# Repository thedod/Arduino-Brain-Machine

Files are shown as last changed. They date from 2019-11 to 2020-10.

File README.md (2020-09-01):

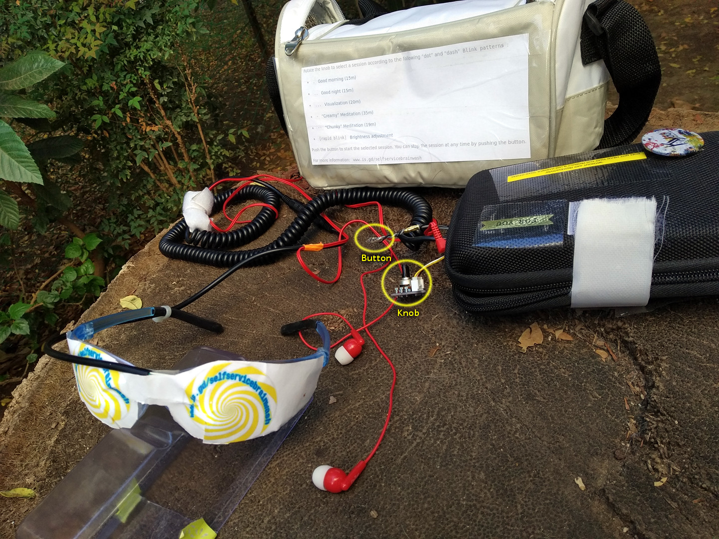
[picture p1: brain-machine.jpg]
Photo gallery (https://pixelfed.tokyo/c/89862350668173312)


For [usage instructions](https://github.com/thedod/Arduino-Brain-Machine/wiki/How-to-use)
and useful brainwave-entrainment related [links](https://github.com/thedod/Arduino-Brain-Machine/wiki/Related-links),
see [the wiki](https://github.com/thedod/Arduino-Brain-Machine/wiki).

#### Difference from fork's origin:

1. The machine can now run 5 different sessions (including the original one). Except for the the original
   session that uses [frequency hopping](https://archive.md/leNZO#selection-1151.0-1151.493) for brainwave entrainment (aka the "chunky" method), the other 4 use smooth frequency transition (aka the "creamy" method), and are based on [Mindplace](https://mindplace.com/) [Proteus](http://mindplacesupport.com/proteus/) sessions (thanks to the admins and members of the mindplace [support forum](http://mindplacesupport.com/forum/) for all the attention and knowledge). There's a 10㏀ potentiometer on pi A0 that is used to select the session.

1. Pin 2 (that used to be the "wake up button") now has 3 functions (depending on state): start / stop / wake (from sleep mode), and the button's interrupt is always attached (not only during sleep mode).

1. More serial debug prints (note that all serial related code is now
   inside `#ifdef DEBUG` blocks).

**Note:** you should download Bhagman's `Tone` library [here](https://github.com/bhagman/Tone#readme).

#### Example breadboard setup
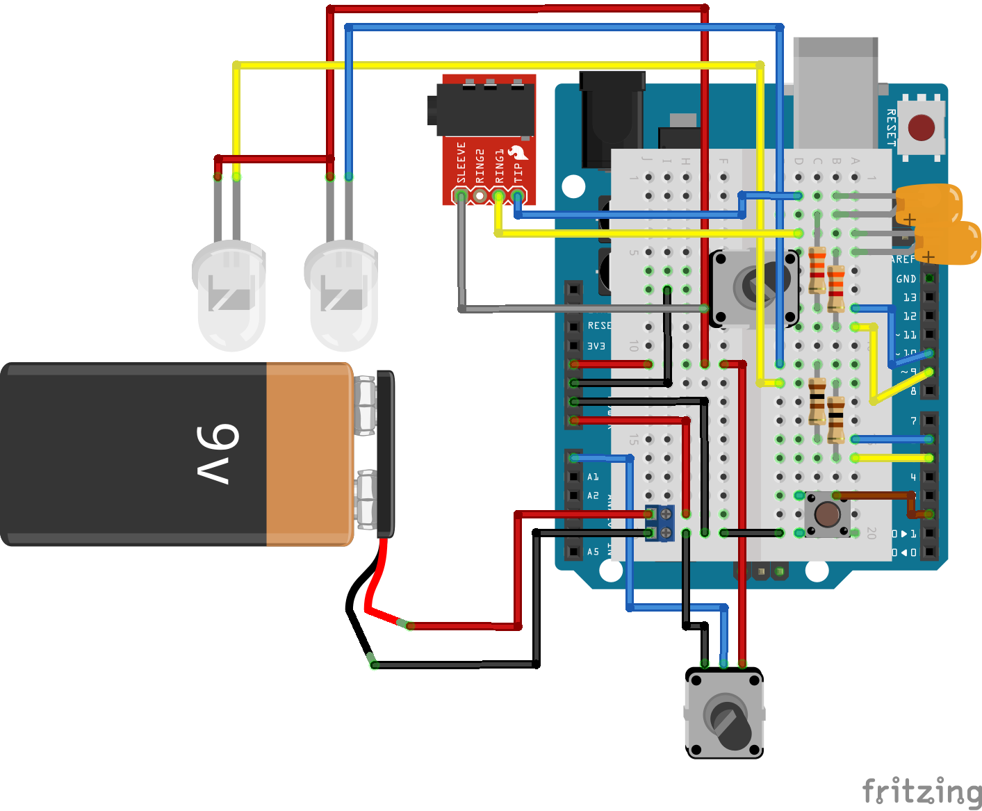
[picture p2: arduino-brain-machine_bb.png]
Example breadboard setup


#### [Photos](https://pixelfed.tokyo/c/89862350668173312)

### New: mono (isochronic) variant

See `Arduino_Brain_Machine_Mono/` folder for code, and `arduino-brain-machine-mono*` for schematics.

### Original README.txt

    Repository: Brain Machine for Arduino
    Attribution: Chris Sparnicht - Laughter on Water - http://low.li
    Creation Date: 2011.01.31
    Last Modification Date: 2011.02.15
    License: Creative Commons 2.5 Attrib. & Share Alike
    
    Derivation and Notes:
    Make sure you have dual wheel potentiometer to reduce
    the volume of the audio with your headset. If you don't, 
    you might damage your ear drums, your arduino or your headset.
    Add a 4.7K ohm resistor from each tone pin to each volume-in
    on the potentiometer to further reduce possibility of physical harm.
    
    This arduino sketch is based on the original Sound & Light Machine 
    by - Mitch Altman - 19-Mar-07 as featured in Make Magazine 10.
    http://makezine.com/10/brainwave/
    
    See notes in code below for how I adapted Mitch Altman's version for Arduino
    
    The sleep coding comes partially from here:
    http://www.arduino.cc/playground/Learning/ArduinoSleepCode
    ***************************************************
    2011.02.20
    Fixed error in breadboard diagram. 
    Added new longer show and gamma frequency (40.4Hz).
    
    2011.02.15
    Added liability notice.
    
    2011.02.14
    Changed to switch/case format for stage choices.
    
    2011.02.14
    Added functions for alternating LED blinking for 
    each of the four stages. So now, there are 
    eight cases: b, B, a, A, t, T, d, and D.
    
    2011.02.14
    I've included a Stereo Eyephone Test sketch 
    and a Stereo Tone Test Sketch. These sketches are purely
    for development purposes, used to confirm preferred programming
    prior to putting it into the Arduino Brain Machine Sketch.
    
    If you're having trouble with Eyephones or Earphones, try
    isolating the cause using one of these simpler sketches.
    
    ***************************************************
    LIABILITY NOTICE:
    ***************************************************
    Light and Sound Machines can be fun for many of us,
    but may be seriously dangerous for those prone to siezures. 
    When in doubt, seek medical attention. 
    You assume all liability for any damage 
    done to your own health, those to whom you expose this
    technology and/or to your equipment when using any notes
    sketches or any associated files within this Git repository.
    
    USE AT YOUR OWN RISK.

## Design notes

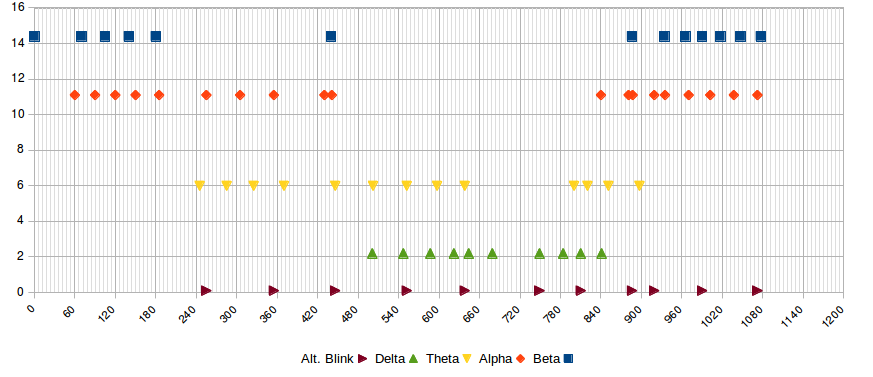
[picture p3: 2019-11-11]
arduino-brain-machine-session.png

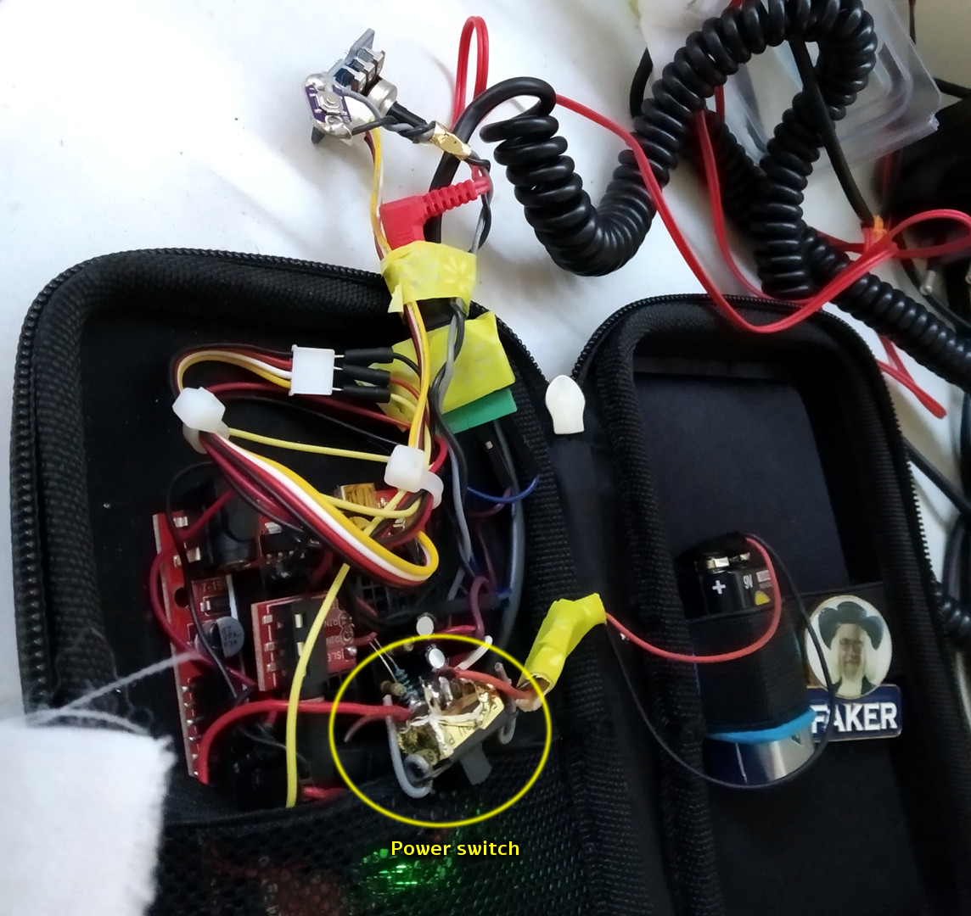
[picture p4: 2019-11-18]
brain-machine-power-switch.jpg

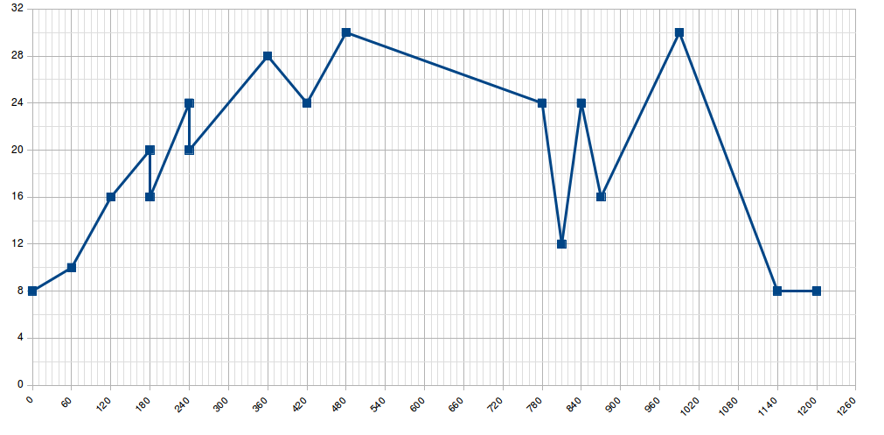
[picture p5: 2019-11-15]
session-visuals-proteus-22.png

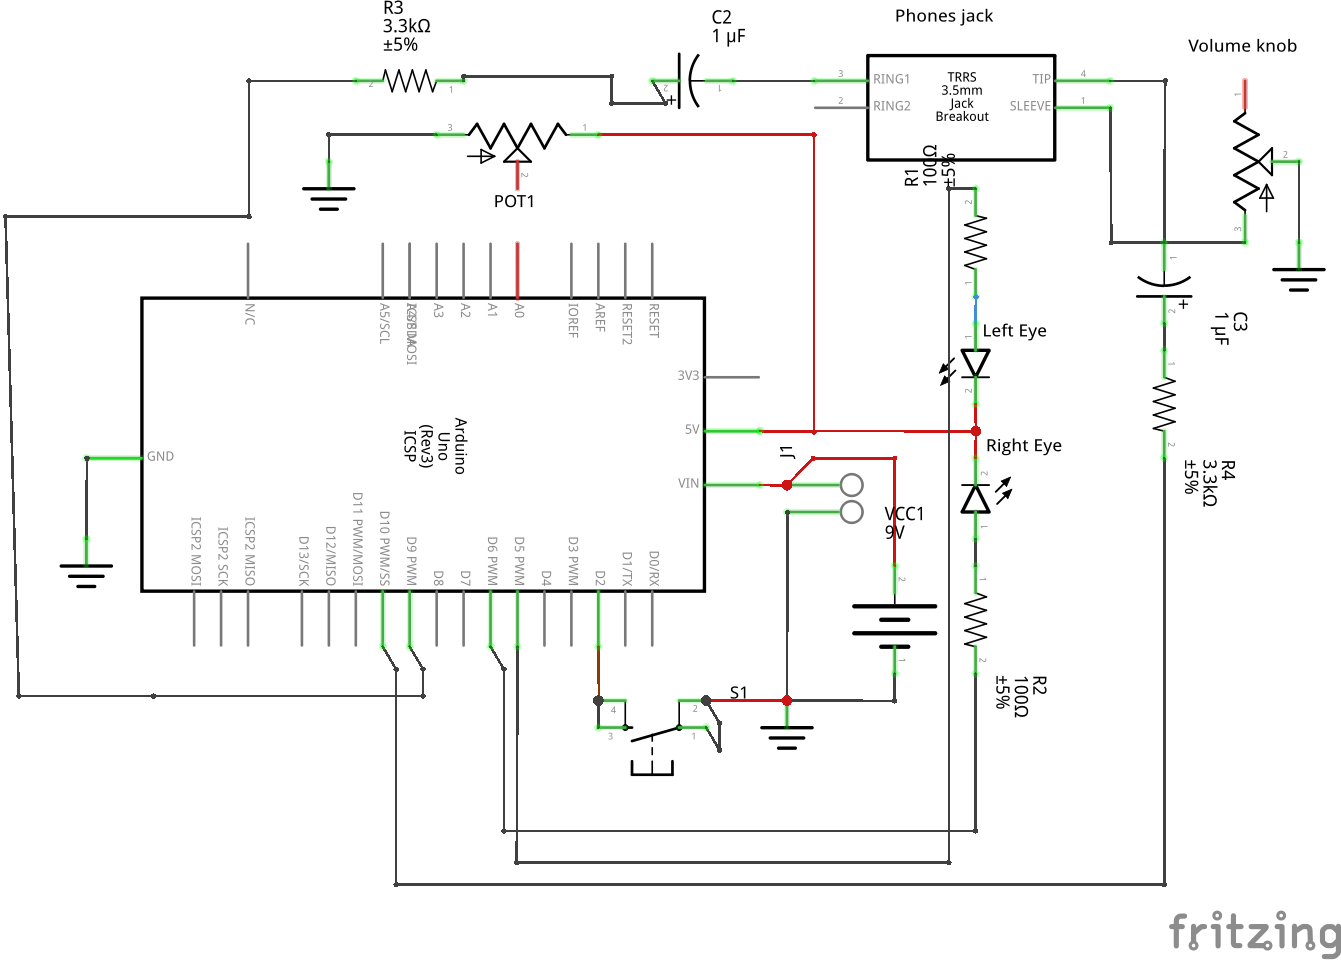
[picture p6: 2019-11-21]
arduino-brain-machine_schem.png

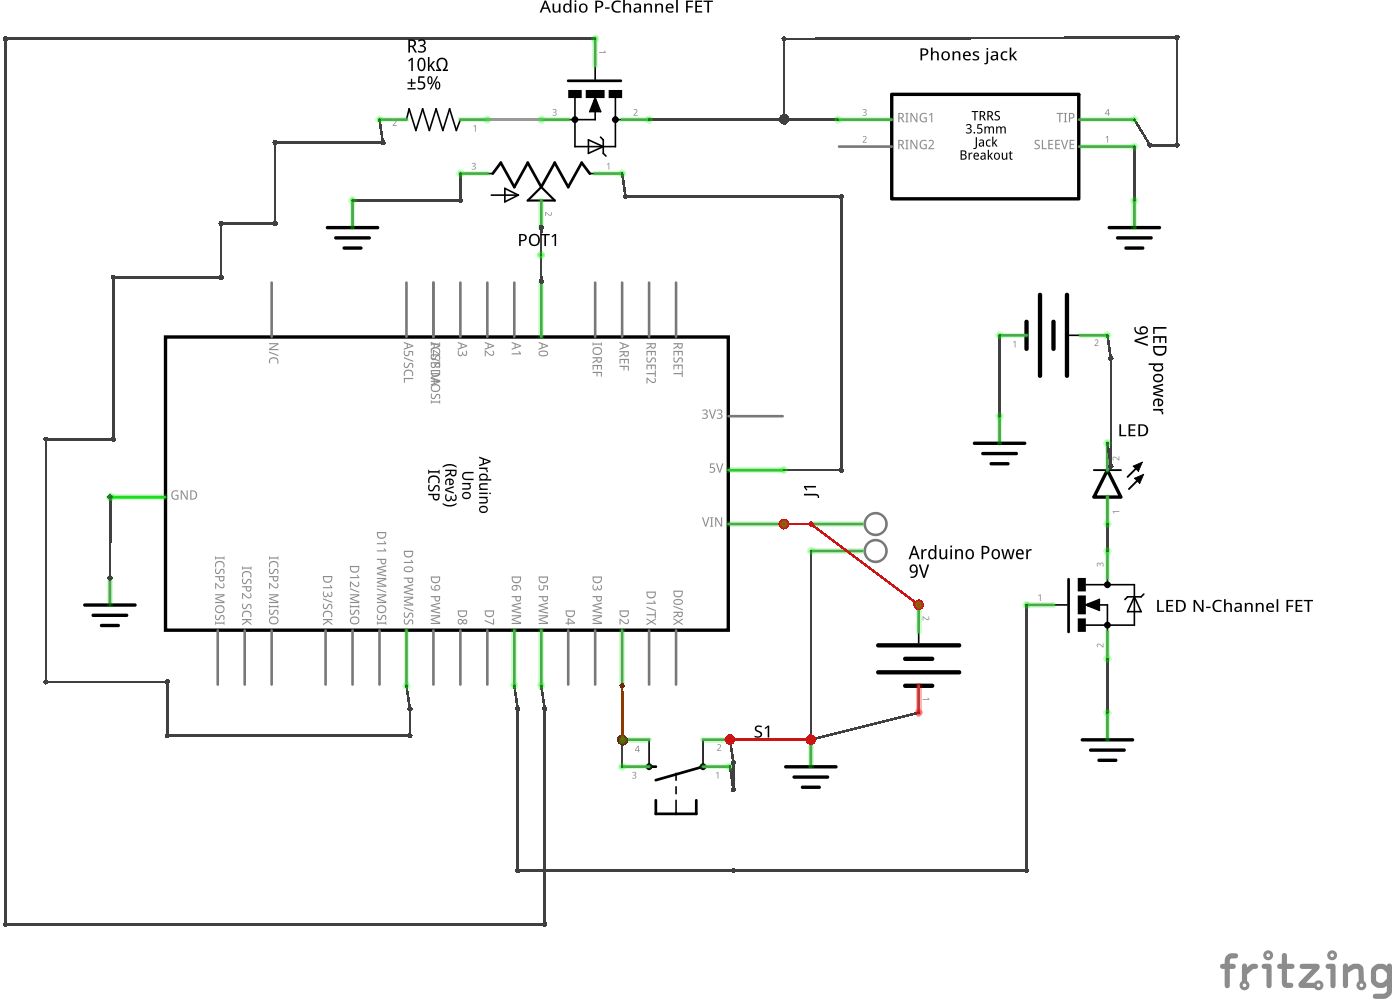
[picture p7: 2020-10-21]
arduino-brain-machine-mono_schem.png

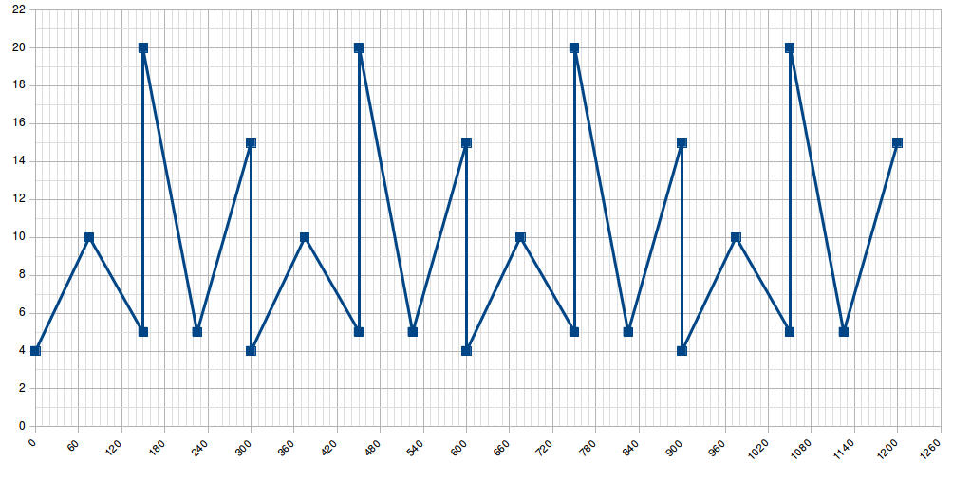
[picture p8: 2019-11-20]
session-visualization-proteus-33.png

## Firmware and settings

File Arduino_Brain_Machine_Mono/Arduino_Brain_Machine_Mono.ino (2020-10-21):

/*************
 * The "mono" variant of the brain machine doesn't use
 * binaural beats to create the illusion of low frequency audio.
 * Instead it uses isochronic tones https://en.wikipedia.org/wiki/Isochronic_tones
 * (turning a single sine wave on and off with a MOSFET)
 * This doesn't require the https://github.com/bhagman/Tone polyphony library
 * (that doesn't work on all duino clones out there, so that's a blessing too)
 * Instead of 2 LEDs, we have a single mosfet that controls a circuit
 * with it's own power supply (e.g. a USB power bank and a USB light).
 * This also means that we ignore the "alt blink" elements of Altmann's
 * "chunky" preset (we use "normal" blinking instead).
 * Enjoy.
 *************/


/***************************************************
  Sketch: Sound & Light Machine for Arduino
  Author: Chris Sparnicht - http://low.li
  Creation Date: 2011.01.31
  Last Modification Date: 2011.02.12
  License: Creative Commons 2.5 Attrib. & Share Alike

  Derivation and Notes:
  Make sure you have audio stereo 10K Ohm potentiometer to reduce
  the volume of the audio with your headset. If you don't,
  you might damage your ear drums, your arduino or your headset.

  Included with this sketch is a png diagram.

  This arduino sketch is based on the original Sound & Light Machine
  by - Mitch Altman - 19-Mar-07 as featured in Make Magazine 10.
  http://makezine.com/10/brainwave/

  See notes in code below for how I adapted Mitch Altman's version for Arduino

  The sleep coding comes partially from here:
  http://www.arduino.cc/playground/Learning/ArduinoSleepCode
***************************************************/

/***************************************************
  SOME INFORMATION ABOUT PROGMEM:
  First, you have to use #include <avr/pgmspace.h> for table arrays - PROGMEM
  The Arduino compiler creates code that will transfer all constants into RAM when the microcontroller
  resets.  This hardward could probably hold all this data in memory, but since the original system
  used a table (chunkybrainwaveTab) that is was too large to transfer into RAM in the original microcontroller,
  we're taking the same approach.  This is accomplished by using the library for PROGMEM.
  (This is used below in the definition for the chunkybrainwaveTab).  Since the
  C compiler assumes that constants are in RAM, rather than in program memory, when accessing
  the chunkybrainwaveTab, we need to use the pgm_read_byte() and pgm_read_dword() macros, and we need
  to use the brainwveTab as an address, i.e., precede it with "&".  For example, to access
  chunkybrainwaveTab[3].bwType, which is a byte, this is how to do it:
   pgm_read_byte( &chunkybrainwaveTab[3].bwType );
  And to access chunkybrainwaveTab[3].bwDuration, which is a double-word, this is how to do it:
   pgm_read_dword( &chunkybrainwaveTab[3].bwDuration );
 ***************************************************/

/***************************************************
  LIBRARIES - Define necessary libraries here.
***************************************************/
#include <avr/pgmspace.h> // for arrays - PROGMEM 
#include <avr/sleep.h> // A library to control the sleep mode
#include <avr/power.h> // A library to control power

/***************************************************
  GLOBALS
  We isolate calls to pins with these globals so we can change
  which pin we'll use i one please, rather than having to search and replace
  in many places.
***************************************************/

// =============== uncomment for serial debugging ===============
// #define DEBUG
// =========================================================================

#define tonePin 10 // tone (gets relayed by audioRelayPin)
#define audioRelayPin 5 // relays tonePin
#define LEDRelayPin 6 // relays LEDs (independent power supply)
#define interruptPin 2 // the input pin where the pushbutton is connected.
#define potPin A0 // user input potentiometer (session selection)

#define LED_ON 255
#define LED_WEAK 31 // for "user-interface" purposes (as opposed to "real" light)
#define LED_OFF 0

// ====== Altman's "chunky" frequency-hopping method =======

/***************************************************
  BRAINWAVE TABLE
  See 'Some information about PROGMEM' above.
  Table of values for meditation start with
  lots of Beta (awake / conscious)
  add Alpha (dreamy / trancy to connect with
      subconscious Theta that'll be coming up)
  reduce Beta (less conscious)
  start adding Theta (more subconscious)
  pulse in some Delta (creativity)
  and then reverse the above to come up refreshed
***************************************************/
struct chunkyBrainwaveElement {
  char bwType;  // 'a' for Alpha, 'b' for Beta, 't' for Theta,'d' for Delta or 'g' for gamma ('0' signifies last entry in table
  // A, B, T, D and G offer alternating flash instead of concurrent flash.
  unsigned long int bwDuration;  // Duration of this Brainwave Type (divide by 10,000 to get seconds)
};

const chunkyBrainwaveElement chunkybrainwaveTab[] PROGMEM = {
  { 'b', 600000 },
  { 'a', 100000 },
  { 'b', 200000 },
  { 'a', 150000 },
  { 'b', 150000 },
  { 'a', 200000 },
  { 'b', 100000 },
  { 'a', 300000 },
  { 'b', 50000 },
  { 'a', 600000 },
  { 't', 100000 },
  { 'A', 300000 },
  { 't', 200000 },
  { 'a', 200000 },
  { 't', 300000 },
  { 'A', 150000 },
  { 't', 600000 },
  { 'a', 100000 },
  { 'b', 10000 },
  { 'a', 50000 },
  { 'T', 550000 },
  { 'd', 10000 },
  { 't', 450000 },
  { 'd', 50000 },
  { 'T', 350000 },
  { 'd', 100000 },
  { 't', 250000 },
  { 'd', 150000 },
  { 'g', 10000 },
  { 'T', 50000 },
  { 'g', 10000 },
  { 'd', 300000 },
  { 'g', 50000 },
  { 'd', 600000 },
  { 'g', 100000 },
  { 'D', 300000 },
  { 'g', 50000 },
  { 'd', 150000 },
  { 'g', 10000 },
  { 't', 100000 },
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
};


/***************************************************
  VARIABLES for tone generator
  The difference in Hz between two close tones can
  cause a 'beat'. The brain recognizes a pulse
  between the right ear and the left ear due
  to the difference between the two tones.
  Instead of assuming that one ear will always
  have a specific tone, we assume a central tone
  and create tones on the fly half the beat up
  and down from the central tone.
  If we set a central tone of 200, we can expect
  the following tones to be generated:
  Hz:      R Ear    L Ear    Beat
  Beta:    192.80   207.20   14.4
  Alpha:   194.45   205.55   11.1
  Theta:   197.00   203.00    6.0
  Delta:   198.90   201.10    2.2

  You can use any central tone you like. I think a
  lower tone between 100 and 220 is easier on the ears
  than higher tones for a meditation or relaxation.
  Others prefer something around 440 (A above Middle C).
  Isolating the central tone makes it easy for
  the user to choose a preferred frequency base.

***************************************************/
float carrierTone = 432.0; // They say it's a cool frequency here: https://attunedvibrations.com/432hz/ (so why not?)

//Blink statuses for function 'blink_LEDs' and 'alt_blink_LEDS
unsigned long int duration = 0;
unsigned long int onTime = 0;
unsigned long int offTime = 0;


// ====== Mindplace.com "creamy" frequency-transition method =======

struct creamyBrainwaveElement {
  int duration;  // Seconds
  float frequency; // Hz
};

const creamyBrainwaveElement proteusGoodMorning04[] = {
  {0, 8}, {120, 16}, {60, 25}, {60, 25}, {60, 20}, {60, 28}, {60, 20}, {60, 28},
  {60, 20}, {60, 28}, {60, 20}, {60, 28}, {60, 20}, {60, 8}, {60, 20}, {0, 0}
};

const creamyBrainwaveElement proteusGoodNight43[] = {
  {0, 9}, {280, 6}, {300, 3}, {200, 5}, {100, 3}, {20, 2}, {0, 0}
};

const creamyBrainwaveElement proteusVisuals22[] = {
  {0, 8}, {60, 10}, {60, 16}, {60, 20}, {0, 16}, {60, 24}, {0, 20}, {120, 28}, {60, 24},
  {60, 30}, {300, 24}, {30, 12}, {30, 24}, {30, 16}, {120, 30}, {150, 8}, {60, 8}, {0, 0}
};

const creamyBrainwaveElement proteusVisuals33[] = {
  {0, 4}, {75, 10}, {75, 5}, {0, 20}, {75, 5}, {75, 15},
  {0, 4}, {75, 10}, {75, 5}, {0, 20}, {75, 5}, {75, 15},
  {0, 4}, {75, 10}, {75, 5}, {0, 20}, {75, 5}, {75, 15},
  {0, 4}, {75, 10}, {75, 5}, {0, 20}, {75, 5}, {75, 15}, {0, 0}
};


const creamyBrainwaveElement proteusMeditation10[] = {
  {0, 16}, {60, 16}, {240, 4}, {360, 4}, {120, 2}, {1080, 2}, {60, 8}, {60, 24},
  {120, 24}, {0, 0}
};


// based on https://isochronic.io/webapp/view.php?id=25
const creamyBrainwaveElement SinePainKiller[] = {
  {0, 0.5}, {90, 1.5}, {90, 0.5}, {90, 1.5}, {90, 0.5}, {90, 1.5}, {90, 0.5}, {90, 1.5},
  {90, 0.5}, {90, 1.5}, {90, 0.5}, {90, 1.5}, {90, 0.5}, {90, 1.5}, {90, 0.5}, {90, 1.5},
  {90, 0.5}, {90, 1.5}, {90, 0.5}, {90, 1.5}, {90, 0.5}, {90, 1.5}, {90, 0.5}, {90, 1.5},
  {90, 0.5}, {90, 1.5}, {90, 0.5}, {90, 1.5}, {90, 0.5}, {90, 1.5}, {90, 0.5}, {90, 1.5},
  {90, 0.5}, {90, 1.5}, {90, 0.5}, {90, 1.5}, {90, 0.5}, {90, 1.5}, {90, 0.5}, {90, 1.5},
  {0, 0}
};


/***************************************************
  Session selection potentiometer
***************************************************/

#define NUM_SESSIONS 6
#define SESSION_GOOD_MORNING 0
#define SESSION_GOOD_NIGHT 1
#define SESSION_VISUALS 2
#define SESSION_MEDITATION 3
#define SESSION_PAINKILLER 4
#define SESSION_MEDITATION_CHUNKY 5

int currentSession;

#define NUM_PROTEUS_SESSIONS 5

const creamyBrainwaveElement *proteusSessions[NUM_PROTEUS_SESSIONS] = {
  proteusGoodMorning04, proteusGoodNight43,
  proteusVisuals33, proteusMeditation10, SinePainKiller
};

int blink_patterns[NUM_SESSIONS] = {
  0B100000000000, // .     SESSION_GOOD_MORNING
  0B100100000000, // ..    SESSION_GOOD_NIGHT
  0B100100100000, // ...   SESSION_VISUALS
  0B111000000000, // -     SESSION_MEDITATION
  0B101010101010, // blink SESSION_PAINKILLER
  0B111001110000, // --    SESSION_MEDITATION_CHUNKY
};

#define BLINK_STATE(n) (((blink_patterns[n]>>n)&1)?HIGH:LOW)

#define BLINK_SEGMENT_DURATION 100 // milliseconds
#define BLINK_NUM_SEGMENTS 12
#define CURRENT_BLINK_SEGMENT ((millis()/BLINK_SEGMENT_DURATION)%BLINK_NUM_SEGMENTS)

int mapPot(int mapMin, int mapMax) {
  // trim a bit of the edge values, because POTs are lousy and might not get there
  return constrain(
           map(analogRead(potPin), 23, 1000, mapMin, mapMax),
           mapMin, mapMax);
}

/***************************************************
  Button interrupt
***************************************************/
#define STATE_READY 0
#define STATE_RUNNING 1
#define STATE_SLEEPING 2
volatile int machineState = STATE_READY;

void buttonInterrupt()
{
  switch (machineState) {
    case STATE_READY:
      machineState = STATE_RUNNING;
      break;
    case STATE_RUNNING:
    case STATE_SLEEPING:
      machineState = STATE_READY; // Back to the normal ready/running cycle
      break;
  }
}


void setLEDs(int state) {
  analogWrite(LEDRelayPin, state);
  analogWrite(audioRelayPin, machineState==STATE_RUNNING ? state : LED_OFF);
}

void blinkSessionSelection(int session) {
  setLEDs(blink_patterns[session] >> CURRENT_BLINK_SEGMENT & 1 ? LED_WEAK : LED_OFF);
}


void setup()  {
#ifdef DEBUG
  Serial.begin(9600);
#endif
  pinMode(tonePin, OUTPUT);
  pinMode(audioRelayPin, OUTPUT);
  pinMode(LEDRelayPin, OUTPUT);
  pinMode(interruptPin, INPUT_PULLUP); // User input (push button)
  pinMode(potPin, INPUT); // User input (potentiometer)
  set_sleep_mode(SLEEP_MODE_PWR_DOWN);
  attachInterrupt(digitalPinToInterrupt(interruptPin), buttonInterrupt, FALLING);
}


/***************************************************
   MAIN LOOP - tells our program what to do.
***************************************************/

void loop() {
  int j;
#ifdef DEBUG
  Serial.println("Waiting for session selection...");
#endif
  while (machineState == STATE_READY) {
    currentSession = mapPot(0, NUM_SESSIONS - 1);
    blinkSessionSelection(currentSession);
    delay(50);
  }
  setLEDs(LED_OFF);


#ifdef DEBUG
  Serial.print("Chose session #");
  Serial.println(currentSession);
#endif
  unsigned long startedAt = millis();
  j = 0;
  if (currentSession < NUM_PROTEUS_SESSIONS) {
    tone(tonePin, carrierTone);
    creamyBrainwaveElement *session = proteusSessions[currentSession];
    float currentFrequency = 0.0;
    while (session[j].frequency > 0.0) { // 0.0 signifies end of table
#ifdef DEBUG
      Serial.print(j);
      Serial.print(' ');
      Serial.print(currentFrequency);
      Serial.print(" -> ");
      Serial.print(session[j].frequency);
      Serial.print(" in ");
      Serial.print(session[j].duration);
      Serial.print(" @");
      Serial.println(millis() - startedAt);
#endif
      if (session[j].duration) {
        float elapsedDms = 0; // decimilliseconds since element's start
        float totalDms = session[j].duration * 10000.0;
        while (elapsedDms < totalDms) {
          float freq = currentFrequency + (session[j].frequency - currentFrequency) * (elapsedDms / totalDms);
          unsigned long halfWaveLength = round(5000.0 / freq);
          setLEDs(LED_ON);
          if (delay_decimiliseconds(halfWaveLength)) {
            break;
          }
          setLEDs(LED_OFF);
          if (delay_decimiliseconds(halfWaveLength)) {
            break;
          }
          elapsedDms += (2.0 * halfWaveLength);
        };
      };
      if (machineState != STATE_RUNNING) {
        break; // interrupt button was pressed
      };
      currentFrequency = session[j].frequency;
      j++;
    };
  } else if (currentSession == SESSION_MEDITATION_CHUNKY) {
    tone(tonePin, carrierTone);
    while (pgm_read_byte(&chunkybrainwaveTab[j].bwType) != '0') {  // '0' signifies end of table
#ifdef DEBUG
      Serial.print(j);
      Serial.print(' ');
      Serial.print((char)(pgm_read_byte(&chunkybrainwaveTab[j].bwType)));
      Serial.print(" @");
      Serial.println(millis() - startedAt);
#endif
      if (do_chunky_brainwave_element(j)) {
        // interrupt button got us out of STATE_RUNNING
        break;
      }
      j++;
    }
  };

  setLEDs(LED_OFF);
  noTone(tonePin);
#ifdef DEBUG
  Serial.print("Done #");
  Serial.print(currentSession);
  Serial.print(' ');
  Serial.println(millis());
#endif
  if (machineState != STATE_READY) {
    // Session finished (we're not here due to an interrupt button push)
    // Shut down everything and put the CPU to sleep
    machineState = STATE_SLEEPING;
#ifdef DEBUG
    Serial.println("Sleeping...");
    delay(1000); // let the dust settle...
#endif
    sleep_enable();          // enables the sleep bit in the mcucr register so sleep is possible. just a safety pin
    sleep_mode();            // here the device is actually put to sleep
    // THE PROGRAM CONTINUES FROM HERE AFTER WAKING UP
    sleep_disable();            // first thing after waking from sleep: disable sleep...
    delay(1000); // let the dust settle...
#ifdef DEBUG
    Serial.println("Woke up.");
#endif
  }
}

/***************************************************
  This function delays the specified number of 1/10 milliseconds
***************************************************/

bool delay_decimiliseconds(unsigned long int dms) {
  // returns true if interrupt button got us out of STATE_RUNNING
  // https://www.arduino.cc/reference/en/language/functions/time/delaymicroseconds/ says
  // "Currently, the largest value that will produce an accurate delay is 16383"
  // so we do each decimilisecond as a separate call
  for (int i = 0; i < dms; i++) {
    delayMicroseconds(100); //
    if (machineState != STATE_RUNNING) {
      return true; // there was an interrupt
    }
  }
  return false;
}

/***************************************************
  This function blinks the LEDs
  (connected to Pin 6, Pin 5 -
  for Left eye, Right eye, respectively)
  and keeps them blinking for the Duration specified
  (Duration given in 1/10 millisecs).
  This function also acts as a delay for the Duration specified.
  In this particular instance, digitalWrites are set
  for common anode, so "on" = LOW and "off" = HIGH.
***************************************************/

bool blink_LEDs( unsigned long int duration, unsigned long int onTime, unsigned long int offTime) {
  // returns true if interrupt button got us out of STATE_RUNNING
  for (int i = 0; i < (duration / (onTime + offTime)); i++) {
    setLEDs(LED_ON);
    // turn on LEDs
    if (delay_decimiliseconds(onTime)) {  //   for onTime
      return true;
    }
    setLEDs(LED_OFF);
    // turn off LEDs
    if (delay_decimiliseconds(offTime)) { //   for offTime
      return true;
    }
  }
  return false;
}

/***************************************************
  This function starts with a central audio frequency and
  splits the difference between two tones
  to create a binaural beat (between Left and Right ears)
  for a Brainwave Element.
  (See notes above for beat creation method.)
***************************************************/

bool do_chunky_brainwave_element(int index) {
  // returns whatever bilnk_LEDs or alt_blink_LEDs returned,
  // i.e. true if interrupt button got us out of STATE_RUNNING
  char brainChr = pgm_read_byte(&chunkybrainwaveTab[index].bwType);

  switch (brainChr) {
    case 'b':
    case 'B':
      // Beta
      return blink_LEDs( pgm_read_dword(&chunkybrainwaveTab[index].bwDuration), 347, 347 );

    case 'a':
    case 'A':
      // Alpha
      return blink_LEDs( pgm_read_dword(&chunkybrainwaveTab[index].bwDuration), 451, 450 );

    case 't':
    case 'T':
      return blink_LEDs( pgm_read_dword(&chunkybrainwaveTab[index].bwDuration), 835, 835 );

    case 'd':
    case 'D':
      return blink_LEDs( pgm_read_dword(&chunkybrainwaveTab[index].bwDuration), 2253, 2253 );

    case 'g':
    case 'G':
      return blink_LEDs( pgm_read_dword(&chunkybrainwaveTab[index].bwDuration), 124, 124 );

    // this should never be executed, since we catch the end of table in the main loop
    default:
      return true;      // end of table
  }
}

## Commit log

2012-03-18 Upgraded to Arduino 1.0
    Changed the .pde to .ino.
2012-03-18 Removed complex timer code in favor of Arduino native function
2019-10-19 Start with both leds on until button press
    Move button from pin 2 to 3
2019-10-19 Added chart and csv for documentation purposes
    [entrainment.csv]
2019-10-21 Decrease LED power 255->63. Add Fritzing schematics.
    [arduino-brain-machine.fzz]
2019-10-23 Move "wait for wake button" code into the loop
    d'Oh
2019-11-13 At last, a "stop" button 😌
2019-11-14 Remove pull up from interrupt button pin
    We now pinMode() it as INPUT_PULLUP, and it seems to be
    sleep-mode-resistant.
    [arduino-brain-machine.fzz]
2019-11-14 Fix schem :s
    [arduino-brain-machine.fzz]
2019-11-15 Major upgrade: add 4 new sessions (and even a setup mode)
    [arduino-brain-machine.fzz]
2019-11-18 Add power switch photo
2019-11-21 Added volume knob to schematics
    [arduino-brain-machine.fzz]
2020-09-01 Add the mono (isochronic) variant
    [arduino-brain-machine-mono.fzz]
2020-10-21 Mute audio FET unless running (don't gate noise)
    [Arduino_Brain_Machine_Mono.ino]
2020-10-21 Audio FET is now P-Channel
    Turns out devices sometimes get ground "leaked" via their power
    sources, and N-Channel FET doesn't really disconnect it.
    [arduino-brain-machine-mono.fzz]
2020-10-21 Breadboard cosmetics
    [arduino-brain-machine-mono.fzz]
